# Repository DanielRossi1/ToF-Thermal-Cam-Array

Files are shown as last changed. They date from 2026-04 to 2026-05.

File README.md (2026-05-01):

# ESP32-S3 Synchronized Sensor Hub

This repository provides a complete implementation for an **ESP32-S3 Synchronized Sensor Hub**, specifically designed for multimodal data acquisition. The current MCU may be not powerful enought to both acquire data and running a local model.

By fusing high-resolution RGB imagery with the spatial depth data from a Time-of-Flight (ToF) array, this system enables robust depth estimation and object detection even in environments where traditional monocular vision fails.

The thermal camera is there because i just liked the idea to include it.

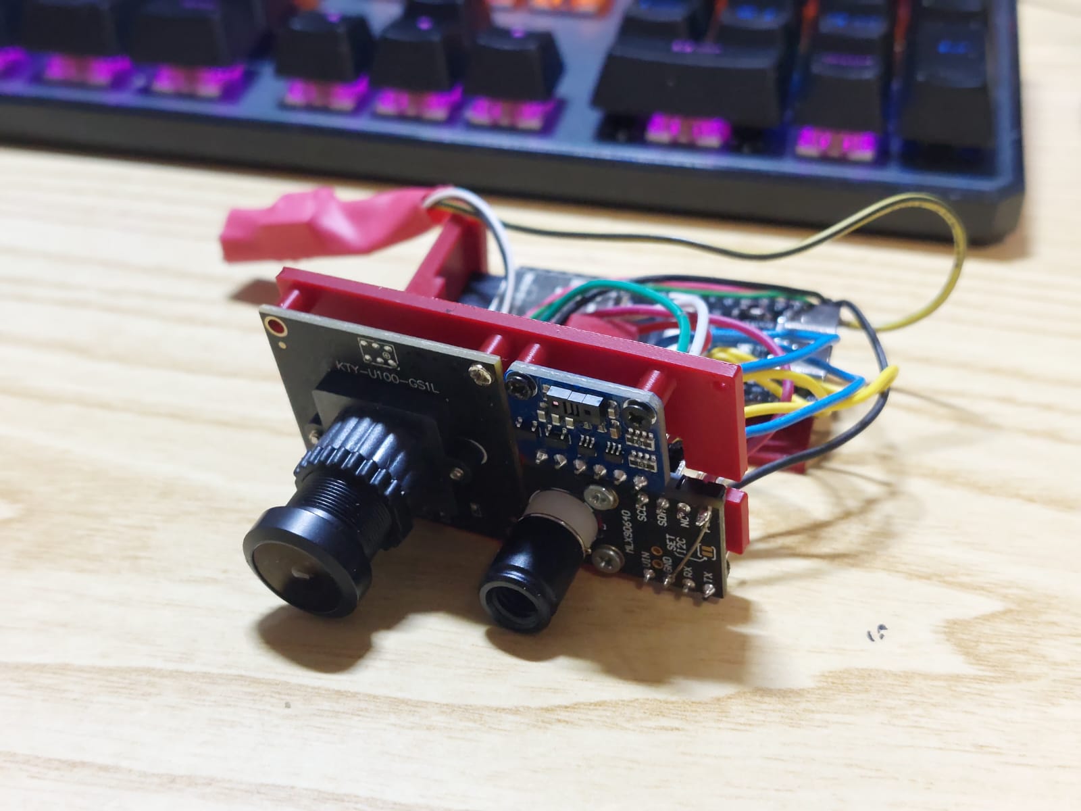
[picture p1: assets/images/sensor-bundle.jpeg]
hardware


---

## Introduction

Monocular depth estimation is an **inherently ill-posed problem**. The transformation from a 2D image plane to 3D coordinates—mapping $\mathbb{R}^2 \rightarrow \mathbb{R}^3$—lacks a unique solution without additional geometric priors or contextual assumptions. In real-world applications, image-only methods frequently fail when encountering:
*   **Extreme lighting conditions** (e.g., high dynamic range or low-light).
*   **Motion blur** during high-speed ego-motion.
*   **Textureless surfaces** (e.g., solid white walls, mirrors, or glass).

To resolve these ambiguities, **multi-modal depth estimation** incorporates active sensors like LiDAR or Radar to provide ground-truth metric constraints. However, these sensors are often prohibitively expensive, bulky, and power-intensive, rendering them unsuitable for edge computing or small-scale robotics.

This project bridges the gap by leveraging **Image + Time-of-Flight (ToF) fusion**. By utilizing the **VL53L8CH** multizone sensor, we provide a solution that is:

*   **Cost-Efficient:** Orders of magnitude more affordable than scanning LiDAR systems.
*   **Low-Latency:** Provides real-world metric anchors at high refresh rates for real-time applications.
*   **Compact:** Ideal for ESP32-S3-based embedded systems where form factor and power efficiency are critical.

---

## The VL53L8CH: Beyond Simple Distance

Unlike traditional single-point ToF sensors that provide a single distance value, the **VL53L8CH** is a high-performance, multizone sensor. It functions essentially as a "low-resolution solid-state LiDAR." Key capabilities include:

*   **Spatial Depth Resolution:** It divides the $45^\circ \times 45^\circ$ square field-of-view into a programmable **$4 \times 4$ or $8 \times 8$ grid**, providing up to 64 independent distance measurements simultaneously.
*   **Per-Zone Confidence Metrics:** For every zone, the sensor outputs a **Sigma** estimate (representing the noise/standard deviation) and a **Signal Rate**, allowing inference models to weigh data points based on their reliability.
*   **Ambient Light Immunity:** It reports ambient light levels for each zone, which is critical for correcting depth artifacts in high-exposure outdoor environments.
*   **Target Status Filtering:** The sensor includes an on-board processing chip that assigns a status code (e.g., "Valid," "Signal Blur," "Wrap Around") to each measurement, ensuring only high-quality ground truth enters your inference pipeline.

---

## Hardware Specification

| Component | Part | Interface | Role |
| :--- | :--- | :--- | :--- |
| **MCU** | ESP32-S3 DevKitC-1 | — | Central synchronization & processing |
| **ToF Array** | VL53L8CH (RTrobot) | I2C (0x52) | $8 \times 8$ metric depth map |
| **Thermal Camera**| MLX90640 | I2C (0x33) | $32 \times 24$ thermal distribution |
| **RGB Camera** | USB UVC Module | USB-OTG | High-res visual reference |
| **PC Connection** | — | USB-UART | Data logging & visualization |

---

## Wiring & Interconnectivity

### I2C Shared Bus
*Requires 4.7kΩ pull-up resistors on SDA and SCL to 3.3V.*

| Signal | ESP32-S3 Pin | VL53L8CH | MLX90640 |
| :--- | :--- | :--- | :--- |
| **SDA** | GPIO 8 | SDA | SDA |
| **SCL** | GPIO 9 | SCL | SCL |
| **3V3** | 3.3V | VCC | VCC |
| **GND** | GND | GND | GND |

### Specialized Connections

| Signal | ESP32-S3 Pin | Component | Description |
| :--- | :--- | :--- | :--- |
| **INT** | GPIO 4 | VL53L8CH | Hardware interrupt for sub-ms sync |
| **XSHUT** | GPIO 5 | VL53L8CH | Hardware reset (optional) |
| **D+ (DP)** | USB-OTG D+ | USB Camera | Direct connection |
| **D- (DM)** | USB-OTG D- | USB Camera | Direct connection |

---

## Technical Configuration (Arduino IDE)

To ensure the USB-OTG port is dedicated exclusively to the camera module, use the following board settings:

| Setting | Value |
| :--- | :--- |
| **Board** | ESP32S3 Dev Module |
| **USB CDC On Boot** | **Disabled** |
| **USB Mode** | **USB-OTG** |
| **PSRAM** | OPI PSRAM |
| **Flash Size** | 8MB (or match your board) |
| **Partition Scheme** | Huge APP (3MB No OTA) |

> [!WARNING]
> **"USB CDC On Boot: Disabled"** is critical. If enabled, Serial communication will hijack the OTG port, causing the camera to fail and the system to hang.

---

## Synchronization Strategy

High-fidelity inference requires zero temporal drift between sensors. We implement a **hardware-triggered interrupt strategy**:

1.  **Trigger:** The VL53L8CH is configured to fire a hardware interrupt (**INT**) at **30Hz**.
2.  **Capture:** Upon the interrupt falling edge, the ESP32-S3 immediately captures the current $8 \times 8$ ToF frame and triggers a DMA-transfer for the UVC camera frame.
3.  **Buffer:** The MLX90640 runs asynchronously at **32Hz**. When the ToF interrupt triggers, we pull the most recent thermal frame from the buffer. 
4.  **Result:** Total temporal jitter between sensors is kept **< 1ms**.

---

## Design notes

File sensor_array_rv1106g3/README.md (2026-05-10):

# RV1106G3 (Luckfox) Synchronized Sensor Hub

This project ports the ESP32-S3 Sensor Hub to the **Luckfox Pico** board with a **Rockchip RV1106G3** SoC, providing significantly more CPU headroom for real-time multi-modal sensor acquisition and on-device inference.

By fusing high-resolution RGB imagery with spatial depth data from a Time-of-Flight (ToF) array, this system enables robust depth estimation and object detection. The thermal camera adds an additional sensing dimension.

---

## Architecture

```
┌──────────────────────────────────────────────────────────┐
│                    Luckfox RV1106G3                       │
│  ┌─────────┐  ┌──────────┐  ┌──────────────────────────┐ │
│  │ VL53L8CH│  │ MLX90640 │  │   USB UVC Camera         │ │
│  │  (ToF)  │  │ (Thermal)│  │   (Global Shutter)       │ │
│  │  I2C    │  │  I2C     │  │   V4L2 / MJPEG           │ │
│  └────┬────┘  └────┬─────┘  └───────────┬──────────────┘ │
│       │            │                     │                │
│  ┌────┴────────────┴─────────────────────┴──────────────┐ │
│  │               sensor_hub (C + pthreads)              │ │
│  │  ┌──────────┐ ┌──────────┐ ┌──────────┐ ┌────────┐  │ │
│  │  │ Loop Thd │ │  TX Thd  │ │  RX Thd  │ │GPIO Thd │  │ │
│  │  │ acquire  │ │  SLIP    │ │  SLIP    │ │ ToF INT │  │ │
│  │  │ sensors  │ │  encode  │ │  decode  │ │  poll() │  │ │
│  │  └──────────┘ └──────────┘ └──────────┘ └────────┘  │ │
│  └────────────────────────┬─────────────────────────────┘ │
│                           │ UART (2M baud)               │
└───────────────────────────┼──────────────────────────────┘
                            │
                    ┌───────┴───────┐
                    │  PC (USB-UART)│
                    │  pc_visualizer│
                    │  (Python/PyQt)│
                    └───────────────┘
```

---

## Directory Structure

```
sensor_array_rv1106g3/
├── main/               # Core application source
│   ├── main.c          # Entry point, thread orchestration
│   ├── hub_protocol.h  # Binary message protocol + SLIP framing
│   ├── hub_frame.h     # Sensor data packet layout
│   ├── hub_config.h    # Pin mappings and tuning constants
│   ├── hub_runtime.h   # Stream mode enum
│   ├── hub_transport.c # UART TX/RX + SLIP encoder/decoder
│   ├── hub_transport.h
│   ├── hub_control.c   # Text command parser/dispatcher
│   ├── hub_control.h
│   ├── i2c_bus.c       # Linux I2C abstraction (/dev/i2c-N)
│   ├── i2c_bus.h
│   ├── tof_vl53l8ch.c  # VL53L8CH ToF sensor driver
│   ├── tof_vl53l8ch.h
│   ├── mlx90640_driver.c # MLX90640 thermal camera driver
│   ├── mlx90640_driver.h
│   ├── v4l2_camera.c   # USB UVC camera via V4L2 + mmap
│   ├── v4l2_camera.h
│   ├── camera_sync.c   # External camera sync (optional)
│   └── camera_sync.h
├── components/
│   ├── STM32duino_VL53L8CH/src/
│   │   ├── platform.c  # Linux I2C platform layer for VL53LMZ API
│   │   ├── platform.h
│   │   ├── platform_config.h
│   │   ├── vl53lmz_api.c/h     # ST VL53LMZ API (firmware+config)
│   │   ├── vl53lmz_buffers.h
│   │   └── vl53lmz_plugin_*.c/h # Xtalk, motion, CNH, thresholds
│   └── Adafruit_MLX90640/
│       ├── MLX90640_API.c/h   # Melexis temperature calculation
│       ├── MLX90640_I2C_Driver.h
│       └── mlx90640_linux_hal.c # Linux I2C HAL for Melexis driver
├── pc_visualizer/     # Python PC-side GUI (copied from ESP project)
│   ├── main.py
│   ├── protocol.py
│   ├── sensor_test.py
│   └── requirements.txt
├── Makefile           # Cross-compilation
├── build.sh           # Build + optional deploy via scp
└── README.md          # This file
```

---

## Thread Architecture

The application uses four POSIX threads (pthreads) mirroring the FreeRTOS task topology of the ESP32 version:

| Thread | Core | Role |
|:--- |:---- |:--- |
| `tx_thread` | — | Dequeues `FrameBuffer` and sends SLIP-encoded frames |
| `rx_thread` | — | Reads raw bytes from UART, feeds SLIP decoder |
| `loop_thread`| — | Acquires ToF + MLX + Camera, assembles frame |
| `gpio_thread`| — | Polls ToF INT GPIO edge via sysfs, sets `g_tof_ready` |

### Synchronisation
- `g_tx_mutex` / `g_tx_cond`: condition variable to signal TX thread when a new frame is ready
- `g_tof_ready` flag: atomic volatile flag set by GPIO thread, consumed by loop thread
- All I2C access serialised via `i2c_bus_lock()`/`unlock()` (pthread mutex)
- V4L2 frame buffer protected by `cam->mutex`

---

## Protocol (Wire Format)

The protocol is **identical** to the ESP32-S3 implementation. See `CONTROL_PROTOCOL.md` in the ESP32 project for full details.

### Framing
- **SLIP** byte-stuffed frames: `END (0xC0)` ... data ... `END (0xC0)`
- Escape bytes: `0xDB 0xDC` for END, `0xDB 0xDD` for ESC

### Message Layout
```
[MsgHeader (24 bytes)] [payload] [CRC32 (4 bytes, LE)]
```

**MsgHeader**: (`packed`, little-endian)
```
uint32_t magic       = 0x53454E53   // 'SENS'
uint16_t version     = 1
uint16_t type        = 1=Frame, 2=Cmd, 3=Resp, 4=Event
uint32_t seq         // sequence number
uint64_t ts_us       // sender timestamp in microseconds
uint32_t payload_len // bytes of payload
```

### Frame Payload (type=1)

The payload is `FrameFixedV1` followed by `cam.len` bytes of JPEG:
```
[frame_seq:4] [hub_ts_us:8] [flags:4] [reserved:4]
[TofDataV1  (variable)]
[MlxDataV1  (1556 bytes)]
[CamSyncV1  (24 bytes)]
[CamDataV1  (24 bytes)]
[JPEG bytes (cam.len bytes)]
```

### Control Commands (type=2)

Plain text commands sent as UTF-8, e.g.:
- `PING` — responds with "PONG"
- `GET INFO` — returns sensor status
- `STREAM enable=0|1 mode=all|tof|mlx|cam|none`
- `SET TOF side=4|8 hz=15 it_ms=50 continuous=1`
- `SET MLX mode=chess res=18 refresh=16`
- `SET CAM enable=1 w=320 h=240 interval_us=83333`
- `DIAG I2C SCAN` — lists I2C devices

---

## Electrical Schematics

### I2C Shared Bus
*Requires 4.7kΩ pull-up resistors on SDA and SCL to 3.3V.*

```
                    ┌──────────────────────┐
                    │    Luckfox Pico       │
                    │    RV1106G3           │
                    │                      │
                    │  Pin 3 (GPIO3_C1) ───┼── SDA ──┬── VL53L8CH SDA
                    │             I2C0     │         │
                    │  Pin 5 (GPIO3_C2) ───┼── SCL ──┼── VL53L8CH SCL
                    │                      │         │
                    │           3.3V ──────┼── VCC ──┼── VL53L8CH VCC
                    │                      │         │   MLX90640 VCC
                    │           GND  ──────┼── GND ──┼── VL53L8CH GND
                    │                      │         │   MLX90640 GND
                    │                      │         │
                    │                      │   MLX90640 SDA ──┤
                    │                      │   MLX90640 SCL ──┤
                    └──────────────────────┘
```

### VL53L8CH (ToF Sensor)

| VL53L8CH Pin | Luckfox Pin  | Description |
|:--- |:--- |:--- |
| SDA | GPIO3_C1 (3) | I2C0 SDA |
| SCL | GPIO3_C2 (5) | I2C0 SCL |
| VCC | 3.3V | Power |
| GND | GND | Ground |
| INT (GPIO1)  | GPIO1_D2 (55)| Data-ready interrupt (falling edge) |
| LPn (XSHUT)  | GPIO1_D3 (56)| Hardware reset (optional) |

### MLX90640 (Thermal Camera)

| MLX90640 Pin | Luckfox Pin  | Description |
|:--- |:--- |:--- |
| SDA | GPIO3_C1 (3) | I2C0 SDA (shared) |
| SCL | GPIO3_C2 (5) | I2C0 SCL (shared) |
| VCC | 3.3V | Power |
| GND | GND | Ground |

### USB UVC Camera

| USB Signal | Luckfox Pin  | Description |
|:--- |:--- |:--- |
| D+ | USB_DP | USB 2.0 host data+ |
| D- | USB_DM | USB 2.0 host data- |
| VBUS | 5V | USB bus power |
| GND | GND | Ground |

### Serial Communication (to PC)

| Signal | Luckfox Pin  | Description |
|:--- |:--- |:--- |
| TX | UART2_TX (8) | 2M baud data to PC |
| RX | UART2_RX (10)| 2M baud data from PC |
| GND | GND | Common ground |

> **Note**: The pin numbers above are for the Luckfox Pico Pro Max. Adjust for your specific Luckfox board variant. The GPIO numbers in `hub_config.h` must match the Linux GPIO numbering (e.g., GPIO1_D2 = chip 1, offset 26 = number 58 on some kernels). Check `/sys/kernel/debug/gpio` on the target.

### External Camera Sync (Optional)

| Signal | Luckfox Pin  | Description |
|:--- |:--- |:--- |
| TRIGGER_OUT  | GPIO1_D4 (57)| Pulse output to camera |
| TRIGGER_IN | GPIO1_D5 (58)| Edge input from camera |

---

## Prerequisites

### Cross-Compilation Toolchain
The Luckfox SDK provides the Rockchip ARM toolchain:

```bash
git clone https://github.com/LuckfoxTECH/luckfox-pico.git
cd luckfox-pico/tools/linux/toolchain/arm-rockchip830-linux-uclibcgnueabihf/
source env_install_toolchain.sh
```

Verify:
```bash
arm-rockchip830-linux-uclibcgnueabihf-gcc --version
```

### Build Dependencies (host)
- `make`, `gcc`, `zlib1g-dev` (for host CRC testing if needed)

### Target Dependencies (on RV1106)
The Luckfox Buildroot image should include:
- Kernel with I2C, UART, USB UVC, GPIO sysfs support
- `/dev/i2c-0` — I2C bus device
- `/dev/ttyS0` (or `/dev/ttyS2`) — UART device
- `/dev/video0` — V4L2 camera device
- GPIO sysfs (enabled in kernel config)

---

## Building

```bash
cd sensor_array_rv1106g3/

# Build
./build.sh

# The binary is at build/sensor_hub
```

### Manual cross-compilation

```bash
export CROSS_COMPILE=arm-rockchip830-linux-uclibcgnueabihf-
make -j$(nproc)
```

### Building with the Luckfox SDK

To integrate into the Luckfox SDK's build system, copy this project into:
```
luckfox-pico/project/app/sensor_array_rv1106g3/
```
Then:
```bash
cd luckfox-pico
./build.sh app
```

---

## Flashing and Running

### 1. Copy binary to board
```bash
# Via scp (adjust IP):
scp build/sensor_hub root@192.168.1.100:/root/

# Or via SD card
```

### 2. Set up GPIO permissions
```bash
# On the Luckfox (as root):
echo 55 > /sys/class/gpio/export    # ToF INT pin
echo in > /sys/class/gpio/gpio55/direction
echo falling > /sys/class/gpio/gpio55/edge

echo 56 > /sys/class/gpio/export    # ToF LPn pin
echo out > /sys/class/gpio/gpio56/direction
echo 1 > /sys/class/gpio/gpio56/value
```

### 3. Run
```bash
chmod +x /root/sensor_hub
/root/sensor_hub
```

Expected output:
```
Sensor Hub for RV1106G3 starting...
Hub running. Press Ctrl+C to stop.
```

### 4. Connect PC Visualizer
```bash
cd pc_visualizer/
pip install -r requirements.txt
python main.py --port /dev/ttyUSB0 --baud 2000000
```

---

## Configuration

All pin assignments and tuning constants are in `main/hub_config.h`:

| Constant | Default | Description |
|:--- |:--- |:--- |
| `I2C_DEVICE_PATH`  | `/dev/i2c-0` | I2C bus device |
| `PIN_TOF_INT` | `55` | ToF interrupt GPIO number |
| `PIN_TOF_LPN` | `56` | ToF reset/low-power GPIO |
| `UART_DEVICE_PATH` | `/dev/ttyS0` | Serial port for PC comm |
| `SERIAL_BAUD` | `2000000` | UART baud rate |
| `USE_UVC_CAMERA` | `1` | Enable V4L2 camera |
| `UVC_AUTOSTART` | `0` | Auto-start camera on boot |
| `CAM_JPEG_MAX` | `55 * 1024` | Max JPEG frame size |

---

## Key Differences from ESP32-S3 Version

| Aspect | ESP32-S3 | RV1106G3 (this port) |
|:--- |:--- |:--- |
| **OS** | FreeRTOS (ESP-IDF) | Linux 5.10 (Buildroot) |
| **Threads** | FreeRTOS tasks | POSIX pthreads |
| **I2C** | ESP-IDF driver API | Linux `/dev/i2c-N` + ioctl |
| **UART** | ESP-IDF UART | Linux termios / termios2 |
| **USB Camera** | usb_stream library | V4L2 + mmap + ioctl |
| **CRC** | esp_crc32_le() | zlib `crc32()` |
| **Timestamp** | esp_timer_get_time | `clock_gettime(MONOTONIC)` |
| **GPIO INT** | ESP-IDF GPIO ISR | Linux sysfs + poll(POLLPRI)  |
| **Memory** | heap_caps_malloc | malloc() |
| **Protocol** | **Identical** | **Identical** |
| **Frame format** | **Identical** | **Identical** |

---

## Performance Notes

- The RV1106G3 Cortex-A7 @ 1.2GHz is significantly faster than ESP32-S3 @ 240MHz
- V4L2 mmap + dedicated capture thread eliminates USB host enumeration delays
- The SLIP protocol supports streaming all three sensors at their maximum rates simultaneously
- Baud rate of 2Mbaud over UART provides ~200KB/s throughput
- Frame rate is governed by the slowest sensor (typically MLX90640 at 16-32Hz)

---

## Troubleshooting

### I2C devices not found
```bash
i2cdetect -y 0          # scan I2C bus
cat /sys/kernel/debug/gpio  # check GPIO states
```

### V4L2 camera not detected
```bash
v4l2-ctl --list-devices
v4l2-ctl -d /dev/video0 --list-formats-ext
```

### Serial port issues
```bash
stty -F /dev/ttyS0 2000000 cs8 -parenb -cstopb raw
```

### Permission denied on GPIO
```bash
echo 55 > /sys/class/gpio/export    # must be root
```

---

## License

This project follows the same license as the parent ESP32-S3 Sensor Hub project. The ST VL53LMZ API and Melexis MLX90640 API retain their original vendor licenses.

---

## Credits

- **STMicroelectronics** — VL53LMZ ULD (Ultra Lite Driver)
- **Melexis** — MLX90640 API
- **Luckfox** — Pico SDK and toolchain
- **Original ESP32-S3 implementation** — `sensor_array_idf/` in this repository

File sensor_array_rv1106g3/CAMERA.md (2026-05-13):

# USB Camera on Luckfox Pico Max — Complete Guide
### Platform: Ubuntu 22.04 (SD card), RV1106G3

---

## What This Guide Covers

Getting a USB UVC camera working on the Luckfox Pico Max, including:
- Flashing Ubuntu to SD card correctly
- Booting from SD instead of NAND
- Enabling USB host mode
- The physical wiring fix that actually solves error -71

---

## Root Cause Summary

> **The Luckfox Pico Max only has a USB-C port. Attaching camera D+ and D- to board's USB pads and powering it via VBUS (board powered via USB-C) does not work, causing `error -71` on every device, including USB drives. This is not a kernel or driver problem.**

The fix is to connect a PD-Trigger to VBUS and power both the board and the camera from the same source. Nothing should be connected then to the USB-C port. Data will be sent via Ethernet.

---

## Prerequisites

- Luckfox Pico Max (RV1106G3)
- MicroSD card (≥8GB)
- Ubuntu host PC
- Bench power supply or stable 5V source
- Jumper wires
- Ubuntu SD image: `Ubuntu_Luckfox_Pico_Max_MicroSD_250313` (or newer)
- Luckfox SDK: `luckfox-pico` cloned from GitHub

---

## Step 1 — Flash Ubuntu to SD Card

The Ubuntu MicroSD image **cannot** be flashed as a single `dd` of `update.img`. Each partition must be written at a specific sector offset defined in `sd_update.txt`.

```bash
cd ~/path/to/Ubuntu_Luckfox_Pico_Max_MicroSD_250313/

sudo umount /dev/sdX* 2>/dev/null

# Wipe first
sudo dd if=/dev/zero of=/dev/sdX bs=1M count=10

# Flash each partition at correct offset
sudo dd if=env.img      of=/dev/sdX seek=$((0x0))      bs=512 conv=notrunc
sudo dd if=idblock.img  of=/dev/sdX seek=$((0x40))     bs=512 conv=notrunc
sudo dd if=uboot.img    of=/dev/sdX seek=$((0x440))    bs=512 conv=notrunc
sudo dd if=boot.img     of=/dev/sdX seek=$((0x640))    bs=512 conv=notrunc
sudo dd if=oem.img      of=/dev/sdX seek=$((0x10640))  bs=512 conv=notrunc
sudo dd if=userdata.img of=/dev/sdX seek=$((0x110640)) bs=512 conv=notrunc
sudo dd if=rootfs.img   of=/dev/sdX seek=$((0x190640)) bs=512 conv=notrunc

sync
sudo eject /dev/sdX
```

> Replace `/dev/sdX` with your actual SD card device (check with `lsblk`).
> The offsets above are from `sd_update.txt` — verify them against your image version if it differs.

---

## Step 2 — Erase NAND Flash

The board boots from NAND by default. You must erase it so the board falls through to SD.

SSH into your existing system first:
```bash
ssh root@<board-ip>
```

Then erase all NAND partitions:
```bash
flash_eraseall /dev/mtd0
flash_eraseall /dev/mtd1
flash_eraseall /dev/mtd2
flash_eraseall /dev/mtd3
flash_eraseall /dev/mtd4
flash_eraseall /dev/mtd5
flash_eraseall /dev/mtd6
```

> **Warning:** This erases the bootloader too. The board will enter MaskRom mode if no SD card is present. Always have the SD card ready before doing this.

Do **not** reboot from SSH — just power off.

---

## Step 3 — Boot from SD

1. Insert the SD card into the Luckfox Pico Max
2. Power on — no button holding required
3. Wait ~15 seconds for Ubuntu to boot

Find the board on your network:
```bash
nmap -sn 192.168.1.0/24 | grep -B1 -A1 -i "luckfox\|rock"
```

SSH in:
```bash
ssh pico@<board-ip>
# default password: luckfox
```

---

## Step 4 — Enable USB Host Mode

The USB port defaults to device/gadget mode (https://wiki.luckfox.com/Luckfox-Pico-Pro-Max/USB). Switch it to host:

```bash
sudo su
echo host > /sys/devices/platform/ff3e0000.usb2-phy/otg_mode
```

Verify:
```bash
cat /sys/devices/platform/ff3e0000.usb2-phy/otg_mode
# Should output: host
```

> This setting does not persist across reboots. To make it permanent, add it to `/etc/rc.local` or a systemd service.

---

## Step 5 — Physical Wiring (The Actual Fix)

**Do not use a USB-C to USB-A adapter.** Even adapters that appear to work for charging will corrupt USB data signals on the RV1106, producing `error -71` on every device.

### Wire the camera directly to the USB-C pads:

| Camera USB-A Pin | Signal | Connect To |
|---|---|---|
| Pin 1 | VBUS (5V) | External 5V supply (bench PSU or PD-Trigger) |
| Pin 2 | D- | USB-C pad D- on board |
| Pin 3 | D+ | USB-C pad D+ on board |
| Pin 4 | GND | Common GND |

**Notes:**
- Power the camera from an external source, not just from the board's VBUS
- Keep wires short (under 10cm), no need to twist them at this length
- USB-C has two orientation sets of D+/D- pads (D1+/D1- and D2+/D2-), try one pair, if it doesn't work try the other or use the multimeter to infer the correct order.
- Check the Luckfox Pico Max schematic at [wiki.luckfox.com](https://wiki.luckfox.com) for exact pad locations

---

## Step 6 — Verify Camera

Watch dmesg live while connecting:
```bash
dmesg -w
```

You should see:
```
usb 1-1: new high-speed USB device number 2 using xhci-hcd
uvcvideo: Found UVC 1.00 device USB Camera (xxxx:xxxx)
```

Check device nodes:
```bash
lsusb          # camera should appear with its ID
ls /dev/video* # multiple nodes will exist
```

Capture a test frame:
```bash
sudo fswebcam -d /dev/video0 test.jpg
```

If `/dev/video0` gives permission denied, run as root or add your user to the `video` group:
```bash
sudo usermod -aG video pico
# then log out and back in
```

If `/dev/video0` is the wrong node (ISP internal), try higher numbers:
```bash
sudo fswebcam -d /dev/video19 test.jpg
sudo fswebcam -d /dev/video20 test.jpg
```

Copy the image to your PC:
```bash
# On your PC:
scp pico@<board-ip>:/home/pico/test.jpg ~/Desktop/test.jpg
```

---

## Recovery: If You Erased NAND Without SD Ready

If the board has no bootable media and enters MaskRom mode:

1. Plug USB-C into PC — no button holding needed in MaskRom
2. Verify detection:
```bash
lsusb | grep "2207"
# Should show: Fuzhou Rockchip Electronics Company
```
3. Reflash NAND using the SDK:
```bash
cd ~/path/to/luckfox-pico
sudo ./rkflash.sh update
```

---

## Making Host Mode Persistent

Create a systemd service:
```bash
sudo nano /etc/systemd/system/usb-host-mode.service
```

```ini
[Unit]
Description=Set USB OTG to host mode
After=network.target

[Service]
Type=oneshot
ExecStart=/bin/sh -c 'echo host > /sys/devices/platform/ff3e0000.usb2-phy/otg_mode'
RemainAfterExit=yes

[Install]
WantedBy=multi-user.target
```

```bash
sudo systemctl enable usb-host-mode
sudo systemctl start usb-host-mode
```

---

## Fixing MAC Address (Stable DHCP IP)

By default the MAC address is random on each boot. Fix it:

```bash
sudo nano /etc/systemd/network/10-eth0.network
```

```ini
[Match]
Name=eth0

[Network]
DHCP=yes

[Link]
MACAddress=xx:xx:xx:xx:xx:xx
```

Replace `xx:xx:xx:xx:xx:xx` with your board's MAC from `cat /sys/class/net/eth0/address`.

```bash
sudo systemctl enable systemd-networkd
sudo reboot
```

---

## Troubleshooting

| Symptom | Cause | Fix |
|---|---|---|
| `error -71` on all USB devices | Bad USB-C adapter | Wire D+/D- directly |
| `error -71` only on camera | Power starvation | Power camera from external supply |
| No `/dev/video*` after camera detected | UVC module not loaded | `sudo modprobe uvcvideo` |
| `lsusb` shows nothing | Host mode not set | Repeat Step 4 |
| Board doesn't boot from SD | NAND not erased | Repeat Step 2 |
| Board enters MaskRom after NAND erase | No SD card present | Insert SD first, see Recovery section |

---

*Tested on: Luckfox Pico Max (RV1106G3), Ubuntu 22.04 SD image 250313, kernel 5.10.160*

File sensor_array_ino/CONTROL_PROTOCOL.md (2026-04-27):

# ESP32-S3 Sensor Hub — Control + Data Protocol (v1)

This firmware streams synchronized sensor frames to the PC **and** accepts runtime configuration commands over the same physical link.

- Physical link (default): **Right USB‑C (CH343p USB‑UART)** @ `2000000` baud
- USB camera: **native USB (GPIO19/20 = D-/D+)** used in host mode via `USB_STREAM`
- Framing: **SLIP** (robust packet boundaries)
- Integrity: **CRC32** (little‑endian, same as ESP-IDF `esp_crc32_le()`)

Important:

- GPIO19/20 are reserved for USB D-/D+. They must not be used as normal GPIO while USB is active.
- External camera sync (trigger/strobe) is only supported if you wire it to different GPIOs and build with `HUB_USE_CAM_SYNC=1`.

## 1) Framing (SLIP)

Each message is sent as a SLIP frame:

- `END = 0xC0`
- `ESC = 0xDB`
- `ESC_END = 0xDC` (represents `END`)
- `ESC_ESC = 0xDD` (represents `ESC`)

On the wire:

- `END` + *encoded bytes* + `END`

Encoding rules:

- byte `0xC0` → `0xDB 0xDC`
- byte `0xDB` → `0xDB 0xDD`
- all other bytes unchanged

## 2) Message layout

Inside the SLIP payload:

```
[MsgHeader][payload...][crc32]
```

### 2.1 Header (`hub::MsgHeader`)

Little-endian, packed:

- `uint32 magic` = `0x53454E53` (`'SENS'`)
- `uint16 version` = `1`
- `uint16 type`
  - `1` = Frame
  - `2` = Cmd
  - `3` = Resp
  - `4` = Event
- `uint32 seq` (sender sequence)
- `uint64 ts_us` (sender timestamp; 0 if not applicable)
- `uint32 payload_len` (bytes)

### 2.2 CRC32

- `uint32 crc32_le` computed over **header + payload** (not including the CRC field)
- Uses ESP-IDF `esp_crc32_le(0, data, len)` semantics

Python note: in many setups `binascii.crc32(data) & 0xffffffff` matches, but if you see CRC mismatches, verify against the device by sending a known packet and comparing.

## 3) Frame messages (`type=1`)

Payload = `hub::FrameFixedV1` followed by `cam.len` bytes of MJPEG.

Key fields:

- `frame_seq`: frame counter
- `hub_ts_us`: timestamp when the hub assembled the frame
- `flags`: bitmask
  - bit0: ToF valid
  - bit1: MLX valid
  - bit2: Camera valid
  - bit3: Camera sync valid

### 3.1 ToF (`VL53L8CH`) data

- Acquisition is **synchronized by the ToF INT pin**.
- Timestamp `tof.ts_us` is taken at the **INT edge** (best timing anchor).
- Provides per-zone **multi-target** data (up to 4 targets/zone).

### 3.2 Thermal (`MLX90640`) data

- Uses Adafruit MLX90640 library.
- Payload contains:
  - ambient temperature `ta_cC` (centi‑°C)
  - 768 pixel temperatures `frame_cC[]` (centi‑°C)

### 3.3 Camera sync (external GPIO, optional)

- In this project, GPIO19/20 are reserved for USB D-/D+ (UVC host).
- Camera sync over extra GPIO is optional and disabled by default (`HUB_USE_CAM_SYNC=0`).
- If you enable cam-sync, use dedicated non-USB pins in `hub_config.h`.

### 3.4 Camera bytes

If UVC support is enabled (`HUB_USE_UVC_CAMERA=1`):

- `cam.cfg.format_fourcc` = `MJPG`
- `cam.len` bytes of JPEG follow immediately after the fixed payload

## 4) Command messages (`type=2`) and responses (`type=3`)

- CMD payload is a UTF‑8 text line (max ~255 bytes recommended).
- RESP payload is UTF‑8 text.

### Supported commands

- `PING`
- `HELP`
- `GET INFO`
- `STREAM enable=0|1 mode=all|tof|mlx|cam|none`
- `SET I2C clock_hz=<n>`
Diagnostics:

- `DIAG I2C SCAN`

ToF:

- `SET TOF side=4|8 hz=<n> it_ms=<n> continuous=0|1`

Thermal:

- `SET MLX mode=chess|interleaved res=16|17|18|19 refresh=0.5|1|2|4|8|16|32|64`

Camera sync:

- `SET CAMSYNC enabled=0|1 period_us=<n> pulse_us=<n>`

UVC camera (only if enabled):

- `SET CAM enable=0|1 w=<n> h=<n> interval_us=<n>`

Notes:

- Camera autostart is disabled by default (`HUB_UVC_AUTOSTART=0`) so ToF/MLX can always boot even if UVC enum is unstable.
- Enable camera at runtime with `SET CAM enable=1`.

## 5) Minimal Python: send a command

This snippet sends one `Cmd` message and prints `Resp/Event` texts.

```python
import serial, struct, binascii

END=0xC0; ESC=0xDB; ESC_END=0xDC; ESC_ESC=0xDD
MAGIC=0x53454E53
VERSION=1
TYPE_CMD=2

def slip_encode(data: bytes) -> bytes:
    out = bytearray([END])
    for b in data:
        if b == END:
            out += bytes([ESC, ESC_END])
        elif b == ESC:
            out += bytes([ESC, ESC_ESC])
        else:
            out.append(b)
    out.append(END)
    return bytes(out)

def build_cmd(seq: int, text: str) -> bytes:
    payload = text.encode('utf-8')
    hdr = struct.pack('<IHHIQI', MAGIC, VERSION, TYPE_CMD, seq, 0, len(payload))
    crc = binascii.crc32(hdr + payload) & 0xffffffff
    return slip_encode(hdr + payload + struct.pack('<I', crc))

ser = serial.Serial('/dev/ttyUSB0', 2000000, timeout=0.2)
ser.write(build_cmd(1, 'GET INFO'))
ser.flush()

# Note: to fully decode responses, implement SLIP decode + header parse.
print('sent')
```

## 6) Practical notes

## 7) Arduino IDE "Tools" configuration (ESP32S3 Dev Module)

Set these exactly for this firmware:

- USB CDC On Boot: `Disabled`
- CPU Frequency: `240MHz (WiFi/BT)`
- USB DFU On Boot: `Disabled`
- Events Run On: `Core 1`
- Flash Mode: `QIO 80MHz`
- Flash Size: `16MB (128Mb)`
- JTAG Adapter: `Disabled`
- Arduino Runs On: `Core 1`
- USB Firmware MSC On Boot: `Disabled`
- Partition Scheme: `Huge APP (3MB No OTA/1MB SPIFFS)`
- PSRAM: `OPI PSRAM`
- Upload Mode: `UART0 / Hardware CDC`
- USB Mode: `USB-OTG (TinyUSB)`

Notes:

- Data streaming to PC uses the CH343p UART path (right USB-C) at `2000000` baud.
- UVC camera uses native USB host on GPIO19/20, so those pins must not be used as generic GPIO.
- If `USB Mode` is set incorrectly, camera host enum may panic in USB HCD (`_uvc_uac_device_enum` / `hcd_urb_enqueue`).

- Once the hub starts, it avoids raw `Serial.println()` to prevent corrupting the binary stream.
- If you change settings, expect 1–2 frames of transient behavior while sensors reconfigure.

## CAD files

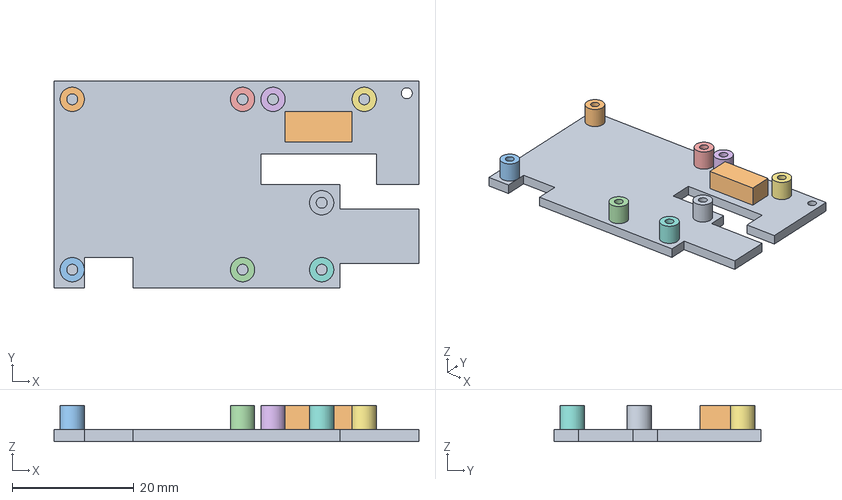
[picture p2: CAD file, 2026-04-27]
assets/3D/sensors-rig.FCStd
60.0 x 34.0 x 6.00 mm
base-sensori
cilindro-camera001
cilindro-camera002
cilindro-camera003
cilindro-camera004
cilindro-ToF001
cilindro-ToF002
cilindro-Thermal001
cilindro-Thermal002
supportino-ToF001

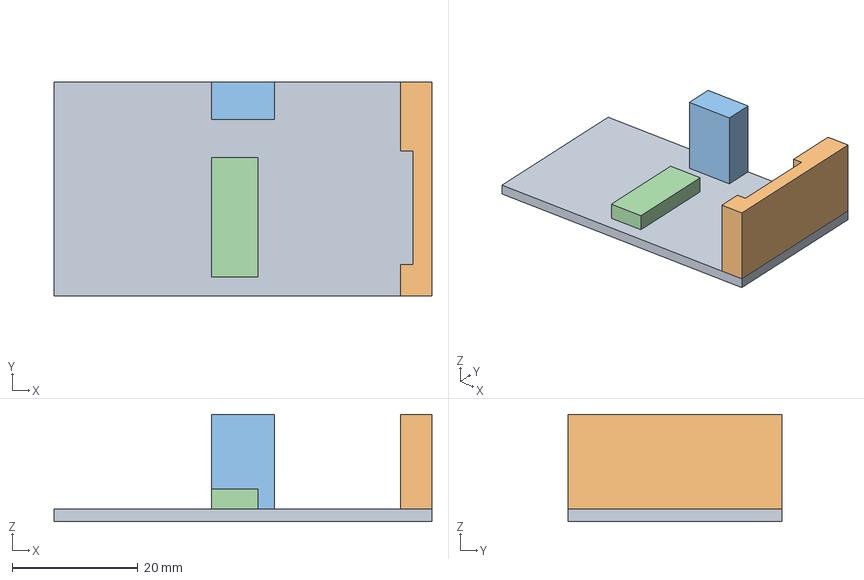
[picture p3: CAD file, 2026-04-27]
assets/3D/esp32-support.FCStd
60.0 x 34.0 x 17.0 mm
base-appoggio
supportino-posteriore
supportino superiore
colonna-supporto

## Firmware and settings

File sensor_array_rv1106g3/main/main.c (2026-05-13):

#include <stdio.h>
#include <stdlib.h>
#include <string.h>
#include <unistd.h>
#include <time.h>
#include <signal.h>
#include <pthread.h>
#include <fcntl.h>
#include <poll.h>
#include <errno.h>
#include <sys/socket.h>
#include <netinet/in.h>
#include <netinet/tcp.h>
#include <arpa/inet.h>
#include <inttypes.h>

#include "hub_config.h"
#include "hub_protocol.h"
#include "hub_frame.h"
#include "hub_runtime.h"
#include "hub_transport.h"
#include "hub_control.h"
#include "i2c_bus.h"
#include "tof_vl53l8ch.h"
#include "mlx90640_driver.h"
#include "camera_sync.h"
#if USE_UVC_CAMERA
#include "v4l2_camera.h"
#endif

// ── Globals ────────────────────────────────────────────────────────────────────

static I2CBus          g_i2c;
static Transport       g_tx;
static TofVl53l8ch     g_tof;
static Mlx90640Driver  g_mlx;
static CameraSync      g_cam_sync;
#if USE_UVC_CAMERA
static V4L2Camera      g_cam;
static int             g_cam_started = 0;
#endif

static volatile StreamMode g_mode = STREAM_MODE_ALL;
static volatile int        g_stream_enabled = 1;

static FrameBuffer    *g_frames[2] = {NULL, NULL};
static int             g_fill_idx = 0;
static uint32_t        g_frame_seq = 0;

static volatile int    g_running = 1;
static volatile int    g_tof_ready = 0;
static volatile uint64_t g_tof_irq_ts_us = 0;

// ToF IRQ pacing (reduces CPU and jitter vs busy-wait)
static pthread_mutex_t g_tof_mutex;
static pthread_cond_t  g_tof_cond;

// Queue for TX thread
static pthread_mutex_t g_tx_mutex = PTHREAD_MUTEX_INITIALIZER;
static pthread_cond_t  g_tx_cond  = PTHREAD_COND_INITIALIZER;
static FrameBuffer    *g_tx_fb = NULL;
static int             g_tx_has_frame = 0;

// Sensor init status
static int g_tof_ok = 0;
static int g_mlx_ok = 0;

// GPIO INT fd
static int g_gpio_fd = -1;

// Forward declarations
static uint64_t now_us(void);

// ── GPIO interrupt thread ──────────────────────────────────────────────────────

static int gpio_export(int pin) {
    char path[64];
    snprintf(path, sizeof(path), "/sys/class/gpio/gpio%d/direction", pin);
    if (access(path, F_OK) == 0) return 0;

    int fd = open("/sys/class/gpio/export", O_WRONLY);
    if (fd < 0) return -1;
    char buf[16];
    int n = snprintf(buf, sizeof(buf), "%d", pin);
    int ret = (write(fd, buf, (size_t)n) < 0) ? -1 : 0;
    close(fd);
    usleep(50000);
    return ret;
}

static int gpio_set_edge(int pin, const char *edge) {
    char path[64];
    snprintf(path, sizeof(path), "/sys/class/gpio/gpio%d/edge", pin);
    int fd = open(path, O_WRONLY);
    if (fd < 0) return -1;
    if (write(fd, edge, strlen(edge)) < 0) { close(fd); return -1; }
    close(fd);
    return 0;
}

static int gpio_set_direction(int pin, const char *dir) {
    char path[64];
    snprintf(path, sizeof(path), "/sys/class/gpio/gpio%d/direction", pin);
    int fd = open(path, O_WRONLY);
    if (fd < 0) return -1;
    if (write(fd, dir, strlen(dir)) < 0) { close(fd); return -1; }
    close(fd);
    return 0;
}

static int gpio_open_value(int pin) {
    char path[64];
    snprintf(path, sizeof(path), "/sys/class/gpio/gpio%d/value", pin);
    return open(path, O_RDONLY);
}

static void *gpio_int_thread(void *arg) {
    (void)arg;
    char buf[2];
    while (g_running) {
        lseek(g_gpio_fd, 0, SEEK_SET);

        struct pollfd pfd = { .fd = g_gpio_fd, .events = POLLPRI | POLLERR };
        int ret = poll(&pfd, 1, 100);
        if (ret < 0) continue;

        if (pfd.revents & POLLPRI) {
            struct timespec ts;
            clock_gettime(CLOCK_MONOTONIC, &ts);
            const uint64_t irq_ts_us = (uint64_t)ts.tv_sec * 1000000ULL +
                                       (uint64_t)ts.tv_nsec / 1000ULL;
            pthread_mutex_lock(&g_tof_mutex);
            g_tof_irq_ts_us = irq_ts_us;
            g_tof_ready = 1;
            pthread_cond_signal(&g_tof_cond);
            pthread_mutex_unlock(&g_tof_mutex);
#if USE_CAM_SYNC
            // Record the edge timestamp for camera sync diagnostics
            g_cam_sync.last_edge_ts_us = irq_ts_us;
#endif

            // Read to clear the interrupt
            lseek(g_gpio_fd, 0, SEEK_SET);
            ssize_t n = read(g_gpio_fd, buf, sizeof(buf));
            (void)n;
        }
    }
    return NULL;
}

// ── TX thread ──────────────────────────────────────────────────────────────────

static void *tx_thread(void *arg) {
    (void)arg;
    static uint64_t last_log_us = 0;
    uint64_t tx_count = 0;
    const uint32_t max_plen = (uint32_t)(sizeof(FrameFixedV1) + CAM_JPEG_MAX);
    uint8_t *payload = (uint8_t *)malloc(max_plen);
    if (!payload) {
        fprintf(stderr, "FATAL: TX payload alloc failed (%u bytes)\n", max_plen);
        g_running = 0;
        return NULL;
    }
    
    while (g_running) {
        pthread_mutex_lock(&g_tx_mutex);
        while (!g_tx_has_frame && g_running) {
            struct timespec ts;
            clock_gettime(CLOCK_REALTIME, &ts);
            ts.tv_nsec += 200L * 1000000L;
            if (ts.tv_nsec >= 1000000000L) {
                ts.tv_sec += ts.tv_nsec / 1000000000L;
                ts.tv_nsec %= 1000000000L;
            }
            pthread_cond_timedwait(&g_tx_cond, &g_tx_mutex, &ts);
        }

        if (!g_running) { pthread_mutex_unlock(&g_tx_mutex); break; }

        FrameBuffer *fb = g_tx_fb;
        if (!fb) {
            g_tx_fb = NULL;
            g_tx_has_frame = 0;
            pthread_mutex_unlock(&g_tx_mutex);
            continue;
        }

        const uint32_t cam_len = fb->fixed.cam.len;
        uint32_t plen = (uint32_t)(sizeof(FrameFixedV1) + cam_len);
        if (plen > max_plen) plen = max_plen;

        const uint32_t seq = fb->fixed.frame_seq;
        const uint64_t ts  = fb->fixed.hub_ts_us;
        memcpy(payload, &fb->fixed, plen);

        g_tx_fb = NULL;
        g_tx_has_frame = 0;
        pthread_mutex_unlock(&g_tx_mutex);

        // If the client socket write blocks for too long it's better to drop
        // frames on the wire rather than block the capture pipeline. The
        // transport layer already uses non-blocking sockets and retries on
        // EAGAIN; keep that behavior but limit excessive sleep here.
        transport_send(&g_tx, MSG_FRAME, seq, ts, payload, plen);
        
        tx_count++;
        uint64_t current_us = now_us();
        if (current_us - last_log_us > 1000000ULL) {  // Log every ~1 sec
            fprintf(stderr, "[TX] Sent %" PRIu64 " frames (last seq=%u, plen=%u)\n",
                    tx_count, seq, plen);
            last_log_us = current_us;
            tx_count = 0;
        }
    }
    free(payload);
    return NULL;
}

// ── RX thread ──────────────────────────────────────────────────────────────────

static SlipDecoder g_slip;

#if !USE_TCP_TRANSPORT
static void *rx_thread(void *arg) {
    (void)arg;
    uint8_t buf[128];
    while (g_running) {
        ssize_t n = read(g_tx.fd, buf, sizeof(buf));
        if (n > 0) {
            slip_decoder_feed(&g_slip, buf, (size_t)n);
        } else if (n == 0) {
            g_running = 0;
            usleep(1000);
        } else if (n < 0 && errno != EAGAIN) {
            usleep(1000);
        }
    }
    return NULL;
}
#endif

// ── Loop thread ────────────────────────────────────────────────────────────────

static uint64_t now_us(void) {
    struct timespec ts;
    clock_gettime(CLOCK_MONOTONIC, &ts);
    return (uint64_t)ts.tv_sec * 1000000ULL + (uint64_t)ts.tv_nsec / 1000ULL;
}

static struct timespec mono_deadline_ms(uint32_t timeout_ms) {
    struct timespec ts;
    clock_gettime(CLOCK_MONOTONIC, &ts);
    ts.tv_nsec += (long)timeout_ms * 1000000L;
    while (ts.tv_nsec >= 1000000000L) {
        ts.tv_nsec -= 1000000000L;
        ts.tv_sec += 1;
    }
    return ts;
}

static void *loop_thread(void *arg) {
    (void)arg;
    uint64_t next_sample_us = 0;

    while (g_running) {
        if (!g_stream_enabled) { usleep(2000); continue; }

        const StreamMode mode   = g_mode;
        const uint64_t    nw_us = now_us();

        uint64_t sample_ts_us = 0;

        // Sampling interval management
        if ((mode == STREAM_MODE_ALL || mode == STREAM_MODE_TOF_ONLY) && g_tof_ok && g_gpio_fd >= 0) {
            // Pace strictly on ToF data-ready IRQ for lowest jitter and CPU.
            pthread_mutex_lock(&g_tof_mutex);
            struct timespec deadline = mono_deadline_ms(120);
            while (!g_tof_ready && g_running) {
                (void)pthread_cond_timedwait(&g_tof_cond, &g_tof_mutex, &deadline);
                if (!g_tof_ready) break;
            }
            if (g_tof_ready) {
                g_tof_ready = 0;
                sample_ts_us = g_tof_irq_ts_us;
            }
            pthread_mutex_unlock(&g_tof_mutex);

            if (!sample_ts_us) {
                // IRQ missing/stalled: avoid a tight loop, fall back to a soft poll cadence.
                if (next_sample_us == 0) next_sample_us = nw_us;
                if (nw_us < next_sample_us) { usleep(2000); continue; }
                next_sample_us = nw_us + 66667;
                sample_ts_us = nw_us;
            }
        } else {
            // Poll-based cadence (used when ToF IRQ not available or other stream modes)
            uint32_t period_us = 50000;
            if ((mode == STREAM_MODE_ALL || mode == STREAM_MODE_TOF_ONLY) && g_tof_ok)
                period_us = 66667; // 15 Hz target for 8x8 ToF

            if (next_sample_us == 0) next_sample_us = nw_us;
            if (nw_us < next_sample_us) { usleep(1000); continue; }
            next_sample_us = nw_us + period_us;
            sample_ts_us = nw_us;
        }

        pthread_mutex_lock(&g_tx_mutex);
        if (g_tx_has_frame) {
            // The network hasn't finished sending the last frame. 
            // Drop this capture cycle to maintain real-time performance.
            pthread_mutex_unlock(&g_tx_mutex);
            usleep(2000);
            continue; 
        }
        pthread_mutex_unlock(&g_tx_mutex);
        // ----------------------

        FrameBuffer *fb = g_frames[g_fill_idx];
        if (!fb) continue;

        fb->fixed.frame_seq  = g_frame_seq++;
        fb->fixed.hub_ts_us  = sample_ts_us ? sample_ts_us : now_us();
        fb->fixed.flags      = 0;
        fb->fixed.reserved   = 0;

        if ((mode == STREAM_MODE_ALL || mode == STREAM_MODE_TOF_ONLY) && g_tof_ok) {
            if (tof_read(&g_tof, &fb->fixed.tof)) {
                fb->fixed.tof.ts_us = sample_ts_us ? sample_ts_us : fb->fixed.tof.ts_us;
                fb->fixed.flags |= FLAG_TOF_VALID;
            } else if (g_frame_seq % 100 == 0) {
                fprintf(stderr, "WARN: ToF read returned no data (frame %u)\n", g_frame_seq);
            }
        }

        if ((mode == STREAM_MODE_ALL || mode == STREAM_MODE_MLX_ONLY) && g_mlx_ok) {
            if (mlx_consume(&g_mlx, &fb->fixed.mlx))
                fb->fixed.flags |= FLAG_MLX_VALID;
            else if (g_frame_seq % 100 == 0)
                fprintf(stderr, "WARN: MLX read returned no data (frame %u)\n", g_frame_seq);
        }
        if ((fb->fixed.flags & FLAG_MLX_VALID) && g_cam_started) {
            int max_temp = 0;
            int hot_x = 16, hot_y = 12; // MLX center

            // Find the hottest pixel in the 32x24 array
            for (int i = 0; i < MLX_PIXELS; i++) {
                if (fb->fixed.mlx.frame_cC[i] > max_temp) {
                    max_temp = fb->fixed.mlx.frame_cC[i];
                    hot_x = i % 32;
                    hot_y = i / 32;
                }
            }

            // If hotter than 28°C (2800 cC), tell the camera to focus AE on this area
            if (max_temp > 2800) {
                g_cam.roi_x = (float)hot_x / 32.0f;
                g_cam.roi_y = (float)hot_y / 24.0f;
                g_cam.roi_w = 0.8f; // 80% weight to the person/heat source
            } else {
                g_cam.roi_w = 0.0f; // Return to global average
            }
        }

        cam_sync_fill(&g_cam_sync, &fb->fixed.cam_sync);
#if USE_CAM_SYNC
        fb->fixed.flags |= FLAG_CAM_SYNC_VALID;
#endif

#if USE_UVC_CAMERA
        uint32_t cam_len   = 0;
        uint64_t cam_ts_us = 0;

        uint64_t cam_min_ts = 0;
        if ((mode == STREAM_MODE_ALL || mode == STREAM_MODE_TOF_ONLY) && g_tof_ok && g_gpio_fd >= 0)
            cam_min_ts = sample_ts_us;

        if ((mode == STREAM_MODE_ALL || mode == STREAM_MODE_CAM_ONLY) && g_cam_started) {
            // When paced by ToF, try to grab a camera frame not older than the ToF IRQ.
            v4l2_camera_snapshot_wait(&g_cam, fb->cam_bytes, CAM_JPEG_MAX,
                                      &cam_len, &cam_ts_us,
                                      cam_min_ts, UVC_SNAPSHOT_WAIT_MS);
        }
        fb->fixed.cam.ts_us          = cam_ts_us;
        fb->fixed.cam.cfg.w          = g_cam.w;
        fb->fixed.cam.cfg.h          = g_cam.h;
        fb->fixed.cam.cfg.format_fourcc = FOURCC_MJPG;
        fb->fixed.cam.len            = cam_len;
        if (cam_len > 0) fb->fixed.flags |= FLAG_CAM_VALID;
#endif

        // Queue for TX
        pthread_mutex_lock(&g_tx_mutex);
        g_tx_fb = fb;
        g_tx_has_frame = 1;
        pthread_cond_signal(&g_tx_cond);
        pthread_mutex_unlock(&g_tx_mutex);
        
        if (g_frame_seq % 100 == 0) {
            fprintf(stderr, "[frame %u] flags=0x%02x tof=%s mlx=%s\n",
                    g_frame_seq,
                    fb->fixed.flags,
                    (fb->fixed.flags & FLAG_TOF_VALID) ? "OK" : "--",
                    (fb->fixed.flags & FLAG_MLX_VALID) ? "OK" : "--");
        }

        g_fill_idx ^= 1;
    }
    return NULL;
}

// ── Boot scan ──────────────────────────────────────────────────────────────────

typedef struct {
    int found;
    int has_mlx_33;
    int has_vl53_29;
} BootI2cScan;

static BootI2cScan g_boot_i2c_scan;

static BootI2cScan scan_i2c(void) {
    BootI2cScan s = {0, 0, 0};
    i2c_bus_lock(&g_i2c);
    // Only probe known sensor addresses to avoid 280 ms I2C timeouts per address
    const uint8_t known[] = { 0x29, 0x33, 0x32, 0x3C };  // VL53, MLX primary, MLX alt, OLED/display
    for (size_t i = 0; i < sizeof(known); i++) {
        if (i2c_bus_probe(&g_i2c, known[i])) {
            s.found++;
            if (known[i] == 0x29) s.has_vl53_29 = 1;
            if (known[i] == 0x33) s.has_mlx_33 = 1;
            printf("I2C: found device at 0x%02X\n", known[i]);
        }
    }
    i2c_bus_unlock(&g_i2c);
    return s;
}

// ── Signal handler ─────────────────────────────────────────────────────────────

static void sig_handler(int sig) {
    (void)sig;
    g_running = 0;
}

// ── TCP transport setup ───────────────────────────────────────────────────────

#if USE_TCP_TRANSPORT
static int set_nonblocking(int fd) {
    int flags = fcntl(fd, F_GETFL, 0);
    if (flags < 0) return -1;
    return fcntl(fd, F_SETFL, flags | O_NONBLOCK);
}

static int tcp_listen_socket(int port) {
    int listen_fd = socket(AF_INET, SOCK_STREAM, 0);
    if (listen_fd < 0) { perror("tcp socket"); return -1; }

    int opt = 1;
    setsockopt(listen_fd, SOL_SOCKET, SO_REUSEADDR, &opt, sizeof(opt));

    struct sockaddr_in addr;
    memset(&addr, 0, sizeof(addr));
    addr.sin_family      = AF_INET;
    addr.sin_addr.s_addr = INADDR_ANY;
    addr.sin_port        = htons((uint16_t)port);

    if (bind(listen_fd, (struct sockaddr *)&addr, sizeof(addr)) < 0) {
        perror("tcp bind"); close(listen_fd); return -1;
    }
    if (listen(listen_fd, 1) < 0) {
        perror("tcp listen"); close(listen_fd); return -1;
    }
    set_nonblocking(listen_fd);
    return listen_fd;
}

static void send_boot_event(void) {
    if (g_tx.fd < 0) return;
    char boot[512];
    snprintf(boot, sizeof(boot),
             "BOOT OK\n"
             "platform=rv1106g3 tof=%d mlx=%d\n"
             "i2c_found=%d mlx_0x33=%d vl53_0x29=%d\n"
             "link=slip+crc32 v=%d\n",
             g_tof_ok, g_mlx_ok,
             g_boot_i2c_scan.found, g_boot_i2c_scan.has_mlx_33, g_boot_i2c_scan.has_vl53_29,
             HUB_VERSION);
    transport_send(&g_tx, MSG_EVENT, 0, now_us(), boot, (uint32_t)strlen(boot));
}
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
int main(void) {
    printf("Sensor Hub for RV1106G3 starting...\n");
    fflush(stdout);

    signal(SIGINT, sig_handler);
    signal(SIGTERM, sig_handler);
    signal(SIGPIPE, SIG_IGN);

    // ── I2C ────────────────────────────────────────────────────────────────
    if (i2c_bus_open(&g_i2c, I2C_DEVICE_PATH) < 0) {
        fprintf(stderr, "FATAL: cannot open I2C bus\n");
        return 1;
    }

    // ── Transport (TCP or UART) ──────────────────────────────────────────
#if USE_TCP_TRANSPORT
    g_tx.fd = -1;
#else
    if (transport_open(&g_tx, UART_DEVICE_PATH, SERIAL_BAUD) < 0) {
        fprintf(stderr, "FATAL: cannot open serial port\n");
        return 1;
    }
#endif

    // ── Boot I2C scan ──────────────────────────────────────────────────────
    printf("Scanning I2C bus for sensors...\n");
    g_boot_i2c_scan = scan_i2c();

    // ── ToF ────────────────────────────────────────────────────────────────
    printf("Initializing ToF sensor...\n");
    g_tof.bus     = &g_i2c;
    g_tof.lpn_pin = PIN_TOF_LPN;
    g_tof_ok      = (tof_begin(&g_tof) == 0);
    printf("ToF sensor: %s\n", g_tof_ok ? "OK" : "FAILED");

    // ── MLX ────────────────────────────────────────────────────────────────
    printf("Initializing MLX sensor...\n");
    g_mlx.bus = &g_i2c;
    g_mlx_ok  = (mlx_begin(&g_mlx) == 0);
    if (g_mlx_ok) {
        if (mlx_start_thread(&g_mlx) != 0) {
            fprintf(stderr, "WARN: MLX thread failed to start\n");
            g_mlx_ok = 0;
        }
    }
    printf("MLX sensor: %s\n", g_mlx_ok ? "OK" : "FAILED");

    // ── Camera sync ────────────────────────────────────────────────────────
    cam_sync_init(&g_cam_sync);

    // ── Timing primitives ───────────────────────────────────────────────────
    pthread_mutex_init(&g_tof_mutex, NULL);
    {
        pthread_condattr_t attr;
        pthread_condattr_init(&attr);
        pthread_condattr_setclock(&attr, CLOCK_MONOTONIC);
        pthread_cond_init(&g_tof_cond, &attr);
        pthread_condattr_destroy(&attr);
    }

#if USE_UVC_CAMERA
    // ── V4L2 camera ────────────────────────────────────────────────────────
    v4l2_camera_init(&g_cam);
#if UVC_AUTOSTART
    g_cam.settings.w = UVC_DEFAULT_W;
    g_cam.settings.h = UVC_DEFAULT_H;
    g_cam.settings.interval_us = UVC_DEFAULT_INTERVAL_US;
    g_cam_started = (v4l2_camera_start(&g_cam, g_cam.settings.w, g_cam.settings.h) == 0);
#else
    g_cam_started = 0;
#endif
#endif

    // ── Frame buffers ──────────────────────────────────────────────────────
    for (int i = 0; i < 2; i++) {
        g_frames[i] = (FrameBuffer *)malloc(sizeof(FrameBuffer));
        if (!g_frames[i]) { fprintf(stderr, "FATAL: frame alloc fail\n"); return 1; }
        memset(g_frames[i], 0, sizeof(FrameBuffer));
    }

    // ── GPIO interrupt for ToF INT pin (non-fatal if pin not available) ─────
    if (gpio_export(PIN_TOF_INT) == 0) {
        usleep(100000);
        gpio_set_direction(PIN_TOF_INT, "in");
        gpio_set_edge(PIN_TOF_INT, "falling");
        g_gpio_fd = gpio_open_value(PIN_TOF_INT);
        fprintf(stderr, "GPIO: INT pin %d ready for interrupts\n", PIN_TOF_INT);
    } else {
        fprintf(stderr, "WARN: cannot export GPIO %d (INT pin) - using polling mode\n", PIN_TOF_INT);
        g_gpio_fd = -1;
    }

    // ── Control context ────────────────────────────────────────────────────
    ControlContext ctx;
    ctx.tx              = &g_tx;
    ctx.i2c             = &g_i2c;
    ctx.tof             = &g_tof;
    ctx.mlx             = &g_mlx;
    ctx.cam_sync        = &g_cam_sync;
#if USE_UVC_CAMERA
    ctx.cam             = &g_cam;
    ctx.cam_started     = &g_cam_started;
#endif
    ctx.stream_enabled  = &g_stream_enabled;
    ctx.mode            = &g_mode;
    hub_control_set_context(&ctx);

    // ── SLIP decoder ───────────────────────────────────────────────────────
    static uint8_t slip_buf[2048];
    slip_decoder_init(&g_slip, slip_buf, sizeof(slip_buf),
                      hub_handle_slip_frame, NULL);

    // ── Start threads ──────────────────────────────────────────────────────
    pthread_t th_tx, th_gpio, th_loop;
#if USE_TCP_TRANSPORT
    pthread_t th_conn;
#else
    pthread_t th_rx;
#endif
    pthread_create(&th_tx,   NULL, tx_thread,       NULL);
#if USE_TCP_TRANSPORT
    pthread_create(&th_conn, NULL, tcp_conn_thread, NULL);
#else
    pthread_create(&th_rx,   NULL, rx_thread,       NULL);
#endif
    pthread_create(&th_loop, NULL, loop_thread,     NULL);
    if (g_gpio_fd >= 0)
        pthread_create(&th_gpio, NULL, gpio_int_thread, NULL);

    printf("Hub running. Press Ctrl+C to stop.\n");
    fflush(stdout);

    // ── Wait ───────────────────────────────────────────────────────────────
    pthread_join(th_loop, NULL);
    pthread_join(th_tx,   NULL);
#if USE_TCP_TRANSPORT
    pthread_join(th_conn, NULL);
#else
    pthread_join(th_rx,   NULL);
#endif
    if (g_gpio_fd >= 0) {
        g_running = 0;
        pthread_join(th_gpio, NULL);
    }

    // ── Cleanup ────────────────────────────────────────────────────────────
#if USE_UVC_CAMERA
    v4l2_camera_deinit(&g_cam);
#endif
    transport_close(&g_tx);
    i2c_bus_close(&g_i2c);

    pthread_cond_destroy(&g_tof_cond);
    pthread_mutex_destroy(&g_tof_mutex);

    for (int i = 0; i < 2; i++) free(g_frames[i]);
    if (g_gpio_fd >= 0) close(g_gpio_fd);

    printf("Hub stopped.\n");
    return 0;
}

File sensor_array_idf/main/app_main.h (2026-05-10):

#pragma once

// Forward declarations for hub classes
namespace hub {
  class I2CBus;
  class TofVl53l8ch;
  class Mlx90640Driver;
  class CameraSync;
  class UvcCamera;
  class Transport;
  class ControlContext;
  class SlipDecoder;
  struct FrameBuffer;
  enum class StreamMode : uint8_t;
  struct FrameFixedV1;
  enum class MsgType : uint8_t;
  constexpr uint32_t kVersion = 2;
  constexpr uint32_t kFourCC_MJPG = 0x4D4A5047;
  constexpr uint32_t kFlagTofValid = 0x01;
  constexpr uint32_t kFlagMlxValid = 0x02;
  constexpr uint32_t kFlagCamSyncValid = 0x04;
  constexpr uint32_t kFlagCamValid = 0x08;
  constexpr uint32_t kCamJpegMax = 65536;
  constexpr uint32_t kSerialBaud = 115200;
  constexpr uint8_t kPinTofInt = 4;
  constexpr uint8_t kPinTofLpn = 5;
  constexpr uint8_t kPinCamSync1 = 19;
  constexpr uint8_t kPinCamSync2 = 20;
  constexpr bool HUB_USE_UVC_CAMERA = true;
  constexpr bool HUB_USE_CAM_SYNC = true;
  constexpr bool HUB_UVC_AUTOSTART = false;
}

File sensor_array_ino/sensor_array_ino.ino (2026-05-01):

/*
 * ESP32-S3-N16R8 — Synchronized Sensor Hub  v2.0
 * ═══════════════════════════════════════════════
 *
 * HARDWARE:
 *   VL53L8CH  ToF 8×8     I2C 0x52   GPIO8=SDA GPIO9=SCL
 *                          LPn=GPIO5  INT=GPIO4
 *   MLX90640  Thermal      I2C 0x33   same bus
 *   USB Camera UVC         Left  USB-C (OTG port)
 *   PC data stream         Right USB-C (CH343p UART port)  ← connect here
 *
 * ARDUINO IDE TOOLS — REQUIRED SETTINGS:
 *   Board:              ESP32S3 Dev Module
 *   USB CDC On Boot:    Disabled          ← CRITICAL for OTG camera
 *   USB Mode:           USB-OTG (TinyUSB) ← CRITICAL for OTG camera
 *   PSRAM:              OPI PSRAM
 *   Partition Scheme:   Huge APP (3MB No OTA / 1MB SPIFFS)
 *   CPU Freq:           240MHz
 *
 * LIBRARIES (Arduino Library Manager):
 *   - STM32duino VL53L8CH      (search "VL53L8CH" → by STMicroelectronics)
 *   - Adafruit MLX90640        (already installed)
 *   - ESP32 USB STREAM         (search "USB_STREAM" → by Espressif)
 *
 * ARCHITECTURE:
 *   Core 1 (loop):  ToF ISR → read ToF + MLX → copy cam → enqueue packet
 *   Core 0:         tx_task → dequeue → write binary packet over UART
 *
 * PACKET FORMAT (binary, little-endian):
 *   [4B]  magic    0xDEADBEEF
 *   [4B]  seq      uint32
 *   [8B]  ts_us    uint64  (µs since boot)
 *   [128B] tof_dist  uint16[64] — zone distances mm
 *   [128B] tof_sigma uint16[64] — zone sigma mm
 *   [64B]  tof_status uint8[64] — target status (5=valid)
 *   [4B]  mlx_w    uint16 (always 32)
 *   [4B]  mlx_h    uint16 (always 24)
 *   [3072B] mlx_frame float32[768] — °C
 *   [4B]  cam_w    uint32
 *   [4B]  cam_h    uint32
 *   [4B]  cam_len  uint32
 *   [cam_len B] cam_jpeg
 *   [4B]  crc32    CRC32 of all above
 */

// ─────────────────────────────────────────────────────────────────────────────
// Modular sensor hub (ESP32-S3)
// - Synchronized acquisition on ToF INT
// - Binary stream framed via SLIP (robust resync) + CRC32
// - Bidirectional commands to tune ToF/MLX/Camera settings
//
// IMPORTANT: do not print raw text to Serial once streaming starts.
// All host-visible messages are sent as framed Event/Resp messages.
// ─────────────────────────────────────────────────────────────────────────────

#include <Arduino.h>

#include "esp_wifi.h"
#include "esp_bt.h"
#include "nvs_flash.h"
#include "esp_timer.h"

#include "freertos/FreeRTOS.h"
#include "freertos/task.h"
#include "freertos/queue.h"

#include "hub_config.h"
#include "hub_control.h"
#include "hub_frame.h"
#include "hub_transport.h"
#include "hub_runtime.h"

#include "camera_sync.h"
#include "i2c_bus.h"
#include "mlx90640_driver.h"
#include "tof_vl53l8ch.h"

#if HUB_USE_UVC_CAMERA
#include "uvc_camera.h"
#endif

// ─────────────────────────────────────────────────────────────────────────────
// Globals
// ─────────────────────────────────────────────────────────────────────────────

static hub::I2CBus g_i2c;
static hub::TofVl53l8ch g_tof(g_i2c, kPinTofLpn);
static hub::Mlx90640Driver g_mlx(g_i2c);
static hub::CameraSync g_cam_sync;

#if HUB_USE_UVC_CAMERA
static hub::UvcCamera* g_cam = nullptr;
static bool g_cam_started = false;
#endif

static HardwareSerial& g_link = Serial;  // CH343 UART when CDC-on-boot is disabled
static hub::Transport g_tx(g_link);

volatile bool g_stream_enabled = true;
static volatile bool g_tof_ready = false;
static volatile uint64_t g_tof_irq_ts_us = 0;

volatile hub::StreamMode hub::g_mode = hub::StreamMode::All;
static uint64_t g_next_sample_us = 0;
static constexpr uint64_t kTofWaitTimeoutUs = 200000;  // 200 ms fallback

static bool g_cam_autostart_pending = false;  // Deferred to loop() after scheduler ready

static hub::FrameBuffer* g_frame[2] = {nullptr, nullptr};
static uint8_t g_fill_idx = 0;
static uint32_t g_frame_seq = 0;

static QueueHandle_t g_tx_queue = nullptr;

static uint8_t g_slip_rx_buf[512];
static hub::ControlContext g_ctrl;
static hub::SlipDecoder g_slip(g_slip_rx_buf, sizeof(g_slip_rx_buf), &hub::handleSlipFrame, &g_ctrl);

struct BootI2cScan {
  uint8_t found = 0;
  bool has_mlx_33 = false;
  bool has_vl53_29 = false;  // 7-bit form (0x52 >> 1)
};

static BootI2cScan scan_i2c_boot() {
  BootI2cScan s;
  auto& w = g_i2c.wire();
  for (uint8_t addr = 1; addr < 127; addr++) {
    w.beginTransmission(addr);
    uint8_t err = w.endTransmission();
    if (err == 0) {
      s.found++;
      if (addr == 0x33) s.has_mlx_33 = true;
      if (addr == 0x29) s.has_vl53_29 = true;
    }
  }
  return s;
}

// ─────────────────────────────────────────────────────────────────────────────
// ISR — ToF data-ready
// ─────────────────────────────────────────────────────────────────────────────
static void IRAM_ATTR tof_int_isr() {
  g_tof_irq_ts_us = (uint64_t)esp_timer_get_time();
  g_tof_ready = true;
}

// ─────────────────────────────────────────────────────────────────────────────
// TX task — Core 0
// ─────────────────────────────────────────────────────────────────────────────
static void tx_task(void* /*arg*/) {
  hub::FrameBuffer* fb = nullptr;
  for (;;) {
    if (xQueueReceive(g_tx_queue, &fb, portMAX_DELAY) != pdTRUE) continue;
    if (!fb) continue;

    const uint32_t payload_len = (uint32_t)(sizeof(hub::FrameFixedV1) + fb->fixed.cam.len);
    (void)g_tx.send(hub::MsgType::Frame,
                    fb->fixed.frame_seq,
                    fb->fixed.hub_ts_us,
                    &fb->fixed,
                    payload_len);
  }
}

// ─────────────────────────────────────────────────────────────────────────────
// RX task — Core 0 (command channel)
// ─────────────────────────────────────────────────────────────────────────────
static void rx_task(void* /*arg*/) {
  uint8_t buf[128];
  for (;;) {
    int avail = g_link.available();
    if (avail <= 0) {
      vTaskDelay(1);
      continue;
    }
    int n = avail;
    if (n > (int)sizeof(buf)) n = (int)sizeof(buf);
    n = g_link.readBytes((char*)buf, n);
    if (n > 0) {
      g_slip.feed(buf, (size_t)n);
    }
  }
}
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

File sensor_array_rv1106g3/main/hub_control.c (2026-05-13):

#include "hub_control.h"
#include <stdio.h>
#include <stdlib.h>
#include <string.h>
#include <ctype.h>

static uint32_t simple_crc32(uint32_t crc, const uint8_t *buf, size_t len) {
    static const uint32_t table[256] = {
        0x00000000,0x77073096,0xEE0E612C,0x990951BA,0x076DC419,0x706AF48F,
        0xE963A535,0x9E6495A3,0x0EDB8832,0x79DCB8A4,0xE0D5E91E,0x97D2D988,
        0x09B64C2B,0x7EB17CBD,0xE7B82D07,0x90BF1D91,0x1DB71064,0x6AB020F2,
        0xF3B97148,0x84BE41DE,0x1ADAD47D,0x6DDDE4EB,0xF4D4B551,0x83D385C7,
        0x136C9856,0x646BA8C0,0xFD62F97A,0x8A65C9EC,0x14015C4F,0x63066CD9,
        0xFA0F3D63,0x8D080DF5,0x3B6E20C8,0x4C69105E,0xD56041E4,0xA2677172,
        0x3C03E4D1,0x4B04D447,0xD20D85FD,0xA50AB56B,0x35B5A8FA,0x42B2986C,
        0xDBBBC9D6,0xACBCF940,0x32D86CE3,0x45DF5C75,0xDCD60DCF,0xABD13D59,
        0x26D930AC,0x51DE003A,0xC8D75180,0xBFD06116,0x21B4F4B5,0x56B3C423,
        0xCFBA9599,0xB8BDA50F,0x2802B89E,0x5F058808,0xC60CD9B2,0xB10BE924,
        0x2F6F7C87,0x58684C11,0xC1611DAB,0xB6662D3D,0x76DC4190,0x01DB7106,
        0x98D220BC,0xEFD5102A,0x71B18589,0x06B6B51F,0x9FBFE4A5,0xE8B8D433,
        0x7807C9A2,0x0F00F934,0x9609A88E,0xE10E9818,0x7F6A0DBB,0x086D3D2D,
        0x91646C97,0xE6635C01,0x6B6B51F4,0x1C6C6162,0x856530D8,0xF262004E,
        0x6C0695ED,0x1B01A57B,0x8208F4C1,0xF50FC457,0x65B0D9C6,0x12B7E950,
        0x8BBEB8EA,0xFCB9887C,0x62DD1DDF,0x15DA2D49,0x8CD37CF3,0xFBD44C65,
        0x4DB26158,0x3AB551CE,0xA3BC0074,0xD4BB30E2,0x4ADFA541,0x3DD895D7,
        0xA4D1C46D,0xD3D6F4FB,0x4369E96A,0x346ED9FC,0xAD678846,0xDA60B8D0,
        0x44042D73,0x33031DE5,0xAA0A4C5F,0xDD0D7CC9,0x5005713C,0x270241AA,
        0xBE0B1010,0xC90C2086,0x5768B525,0x206F85B3,0xB966D409,0xCE61E49F,
        0x5EDEF90E,0x29D9C998,0xB0D09822,0xC7D7A8A8,0x59B33D17,0x2EB40D81,
        0xB7BD5C3B,0xC0BA6CAD,0xEDB88320,0x9ABFB3B6,0x03B6E20C,0x74B1D29A,
        0xEAD54739,0x9DD277AF,0x04DB2615,0x73DC1683,0xE3630B12,0x94643B84,
        0x0D6D6A3E,0x7A6A5AA8,0xE40ECF0B,0x9309FF9D,0x0A00AE27,0x7D079EB1,
        0xF00F9344,0x8708A3D2,0x1E01F268,0x6906C2FE,0xF762575D,0x806567CB,
        0x196C3671,0x6E6B06E7,0xFED41B76,0x89D32BE0,0x10DA7A5A,0x67DD4ACC,
        0xF9B9DF6F,0x8EBEEFF9,0x17B7BE43,0x60B08ED5,0xD6D6A3E8,0xA1D1937E,
        0x38D8C2C4,0x4FDFF252,0xD1BB67F1,0xA6BC5767,0x3FB506DD,0x48B2364B,
        0xD80D2BDA,0xAF0A1B4C,0x36034AF6,0x41047A60,0xDF60EFC3,0xA867DF55,
        0x316E8EEF,0x4669BE79,0xCB61B38C,0xBC66831A,0x256FD2A0,0x5268E236,
        0xCC0C7795,0xBB0B4703,0x220216B9,0x5505262F,0xC5BA3BBE,0xB2BD0B28,
        0x2BB45A92,0x5CB30A04,0xC2D7FFA7,0xB5D0CF31,0x2CD99E8B,0x5BDEAE1D,
        0x9B64C2B0,0xEC63F226,0x756AA39C,0x026D930A,0x9C0906A9,0xEB0E363F,
        0x72076785,0x05005713,0x95BF4A82,0xE2B87A14,0x7BB12BAE,0x0CB61B38,
        0x92D28E9B,0xE5D5BE0D,0x7CDCEFB7,0x0BDBDF21,0x86D3D2D4,0xF1D4E242,
        0x68DDB3F8,0x1FDA836E,0x81BE16CD,0xF6B9265B,0x6FB077E1,0x18B74777,
        0x88085AE6,0xFF0F6A70,0x66063BCA,0x11010B5C,0x8F659EFF,0xF862AE69,
        0x616BFFD3,0x166CCF45,0xA00AE278,0xD70DD2EE,0x4E048354,0x3903B3C2,
        0xA7672661,0xD06016F7,0x4969474D,0x3E6E77DB,0xAED16A4A,0xD9D65ADC,
        0x40DF0B66,0x37D83BF0,0xA9BCAE53,0xDEBB9EC5,0x47B2CF7F,0x30B5FFE9,
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
    };
    crc ^= 0xFFFFFFFF;
    for (size_t i = 0; i < len; i++)
        crc = table[(crc ^ buf[i]) & 0xFF] ^ (crc >> 8);
    return crc ^ 0xFFFFFFFF;
}

static ControlContext *g_ctx = NULL;

void hub_control_set_context(ControlContext *ctx) {
    g_ctx = ctx;
}
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

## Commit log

2026-04-27 tof works - thermal works - camera not works
    [esp32-support.FCStd, sensors-rig.FCStd]
2026-05-01 GS camera still not working
    [partitions.csv]
2026-05-01 updated correct code but camera does not start
    [esp32-support.FCStd, sensors-rig.FCStd]
2026-05-10 switched to luckfox because of usb bandwidth
2026-05-13 fixed bugs - added calibration page and config page
    [hub_config.h, hub_control.c, main.c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]
2026-05-13 trying to add autoexposure bc this camera sucks
2026-05-17 trying to calibrate tof with camera
2026-05-18 calibration kinda works(?)
2026-05-20 refactor calibration and fixed gui
